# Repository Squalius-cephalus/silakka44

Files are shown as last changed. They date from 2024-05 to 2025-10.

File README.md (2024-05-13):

# Silakka44

Silakka44 is a RP2040 based 44-key column staggered split keyboard. PCB uses hotswap sockets. Design is inpired from REVIUNG41 and Corne keyboards.

PCB is designed for MX style key switches. Current top plate only supports MX style switches. 5-pin switches is supported.

[QMK](https://github.com/qmk/qmk_firmwarehttp:// "QMK") and [Vial](https://github.com/vial-kb/vial-qmk "Vial") firmwares has very barebones key mapping. Good for quick testing.

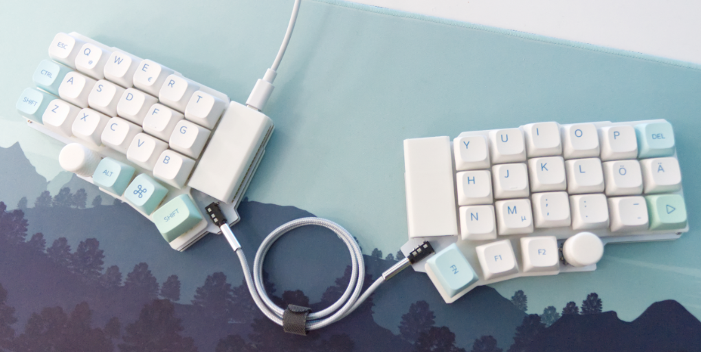
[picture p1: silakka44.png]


You can find build guide [here.](https://github.com/Squalius-cephalus/silakka44/blob/main/buildguide/README.md "here.")

PCB design uses footprints from [ScottoKeebs](https://github.com/joe-scotto/scottokeebs/tree/main/Extras/ScottoKicad "ScottoKeebs") and [kbd library.](https://github.com/foostan/kbd "kbd library.")

### Bugs
Sometimes the encoder buttons are "stuck" when the keyboard is connected to the computer. Pressing those once fixes the problem.

### TODO
1. Redo traces
2. Fix bugs

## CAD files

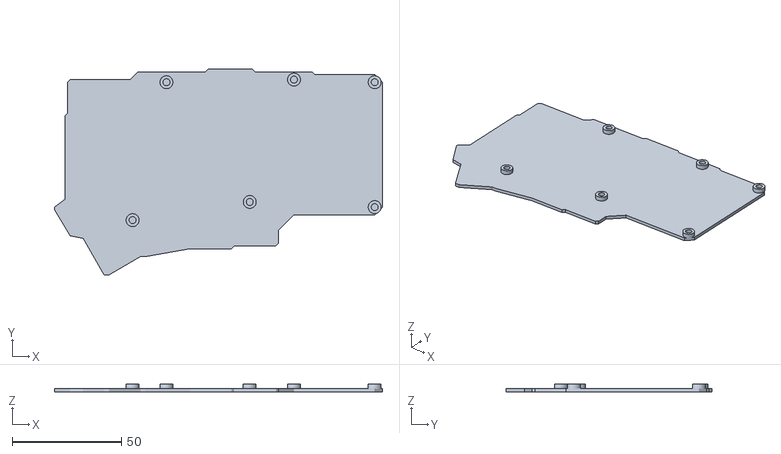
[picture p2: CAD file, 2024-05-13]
stl/silakka42_bottom_right.stl
150.0 x 94.0 x 3.76

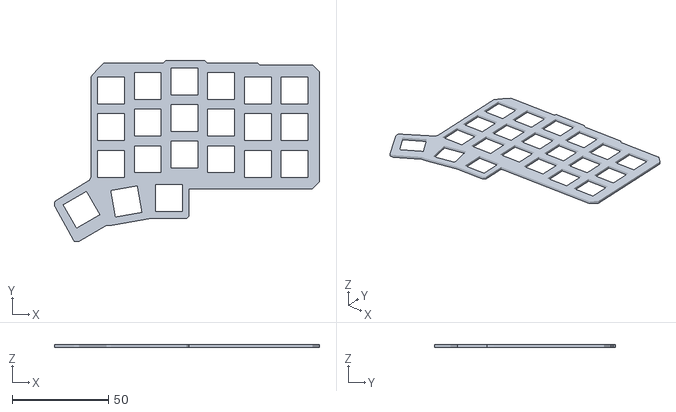
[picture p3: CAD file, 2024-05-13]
stl/silakka44_top_right.stl
137.6 x 94.0 x 1.50

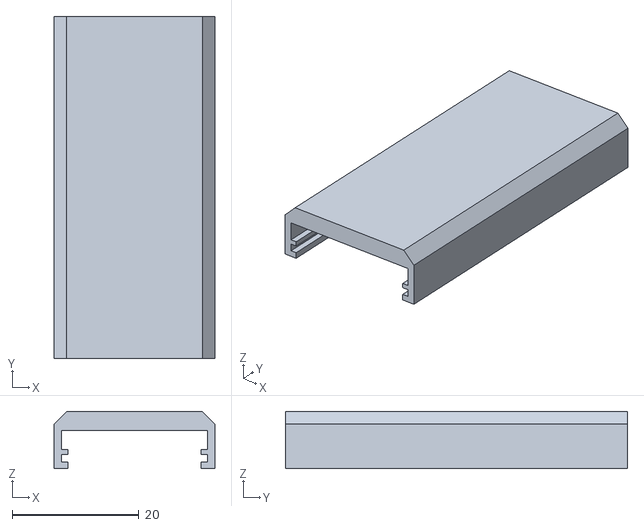
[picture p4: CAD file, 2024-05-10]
stl/raspberry_pi_pico_cover.stl
25.4 x 54.0 x 9.00

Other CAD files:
stl/silakka42_bottom_left.stl
stl/silakka44_top_left.stl

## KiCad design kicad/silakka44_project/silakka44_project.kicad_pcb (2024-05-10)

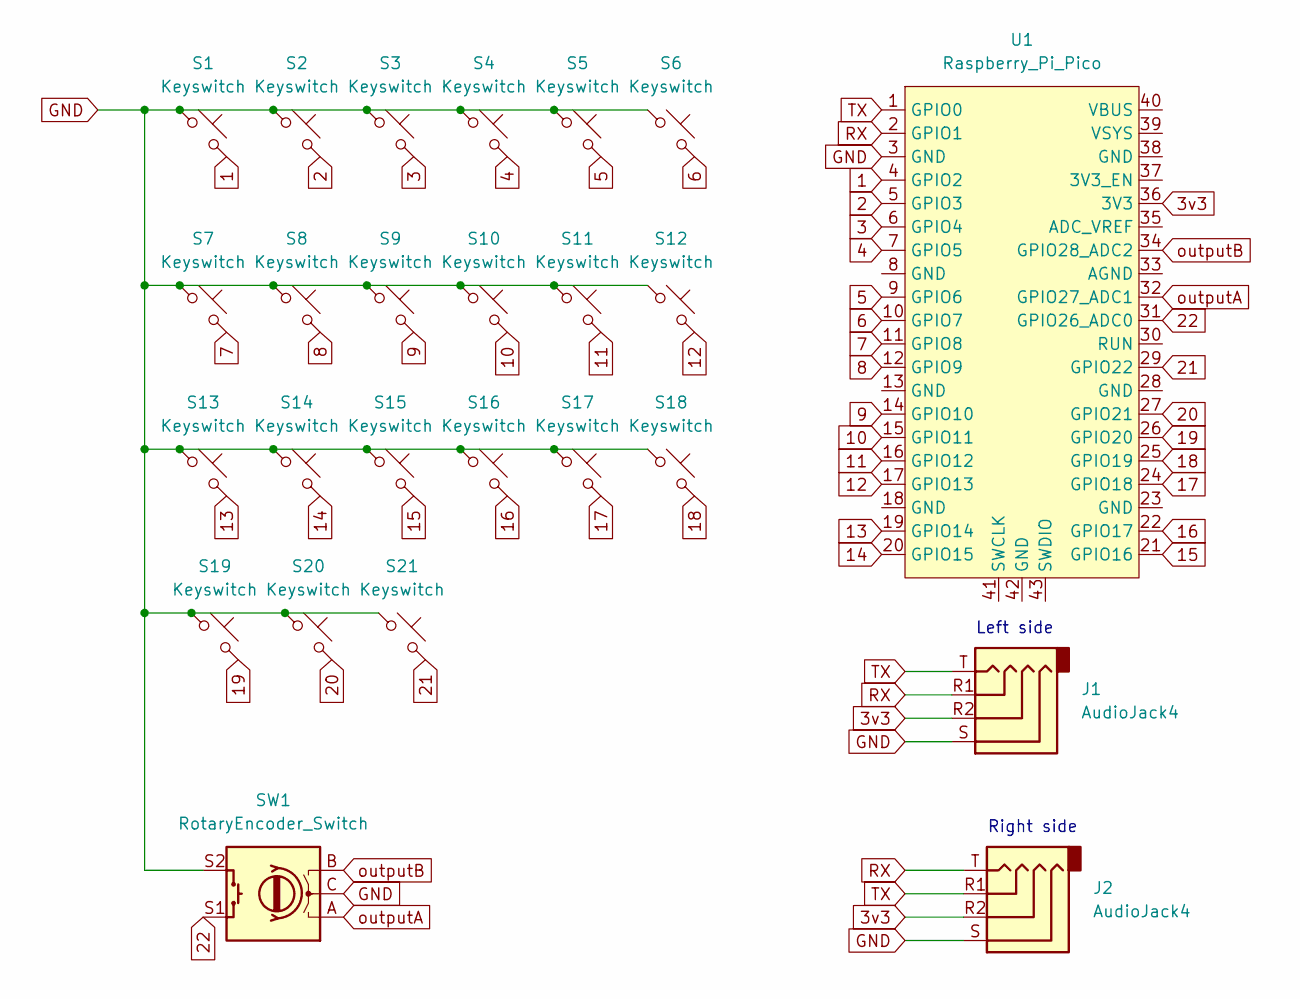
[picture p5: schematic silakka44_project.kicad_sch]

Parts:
J1, J2: AudioJack4; Jack_3.5mm_PJ320D_Horizontal
S1, S2, S3, S4, S5, S6, S7, S8, S9, S10, S11, S12, S13, S14, S15, S16, S17, S18, S19, S20, S21: Keyswitch; CherryMX_MidHeight_Hotswap
SW1: RotaryEncoder_Switch; RotaryEncoder_EC11
U1: Raspberry_Pi_Pico

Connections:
1: S1.2, U1.4 (GPIO2)
2: S2.2, U1.5 (GPIO3)
3: S3.2, U1.6 (GPIO4)
3v3: J1.R2, J2.R2, U1.36 (3V3)
4: S4.2, U1.7 (GPIO5)
5: S5.2, U1.9 (GPIO6)
6: S6.2, U1.10 (GPIO7)
7: S7.2, U1.11 (GPIO8)
8: S8.2, U1.12 (GPIO9)
9: S9.2, U1.14 (GPIO10)
10: S10.2, U1.15 (GPIO11)
11: S11.2, U1.16 (GPIO12)
12: S12.2, U1.17 (GPIO13)
13: S13.2, U1.19 (GPIO14)
14: S14.2, U1.20 (GPIO15)
15: S15.2, U1.21 (GPIO16)
16: S16.2, U1.22 (GPIO17)
17: S17.2, U1.24 (GPIO18)
18: S18.2, U1.25 (GPIO19)
19: S19.2, U1.26 (GPIO20)
20: S20.2, U1.27 (GPIO21)
21: S21.2, U1.29 (GPIO22)
22: SW1.S1, U1.31 (GPIO26_ADC0)
GND: J1.S, J2.S, S1.1, S2.1, S3.1, S4.1, S5.1, S6.1, S7.1, S8.1, S9.1, S10.1, S11.1, S12.1, S13.1, S14.1, S15.1, S16.1, S17.1, S18.1, S19.1, S20.1, S21.1, SW1.C, SW1.S2, U1.3 (GND)
RX: J1.R1, J2.T, U1.2 (GPIO1)
TX: J1.T, J2.R1, U1.1 (GPIO0)
outputA: SW1.A, U1.32 (GPIO27_ADC1)
outputB: SW1.B, U1.34 (GPIO28_ADC2)

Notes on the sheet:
Right side
Left side

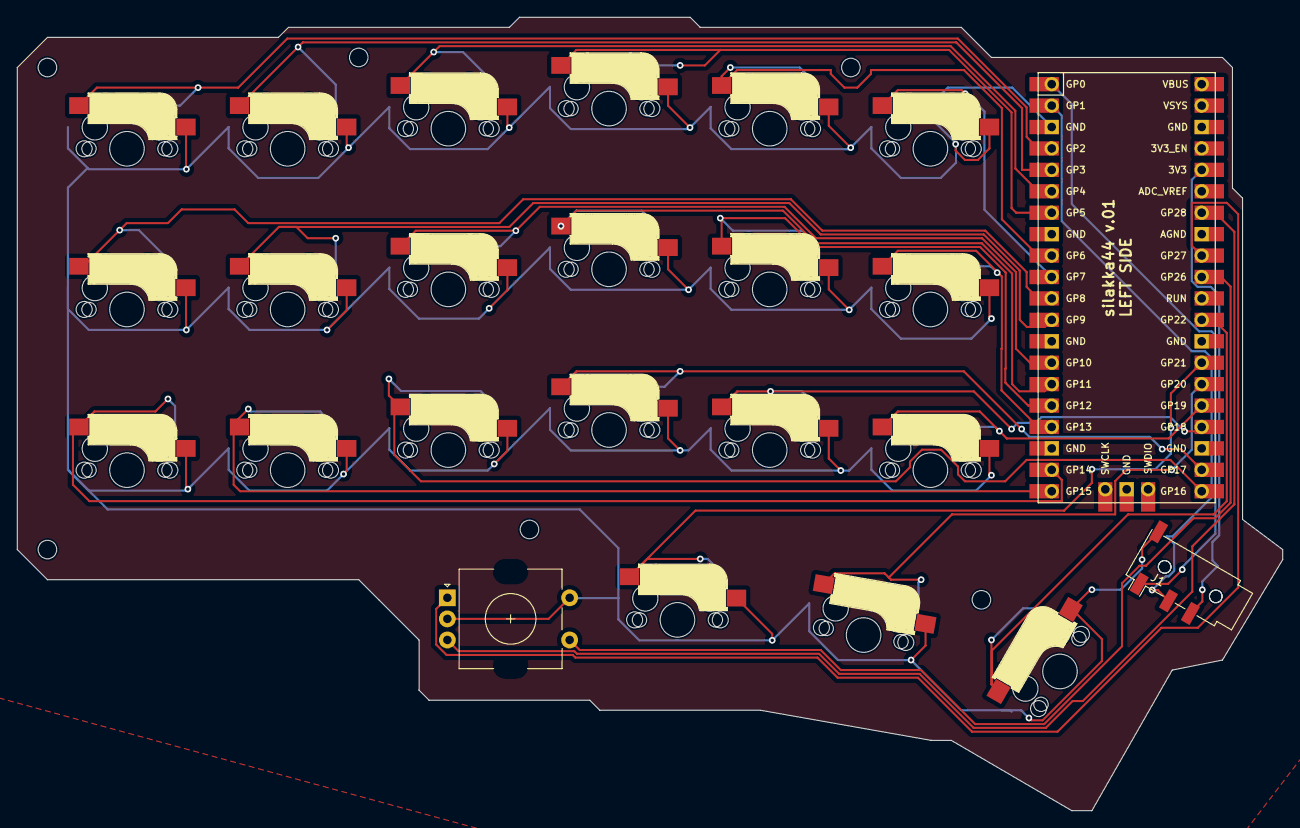
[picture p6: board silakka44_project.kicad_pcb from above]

Board: 2 copper layers, 150.0 x 94.1 mm, 25 parts (1 on the bottom side), 28 nets.

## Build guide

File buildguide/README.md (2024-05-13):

# Silakka44 - Build Guide

### Bill of materials
- **42x** MX compatible key switches
- **40x** 1u keycaps
- **2x** 1.5u keycap
- **42x** Kailh Hotswap Sockets
- **2x** Raspberry Pi Pico or pin compatible clone
- **2x** PJ320D audio sockets
- **2x** EC11 encoders
- **1x** TRRS audio cable
- **12x** M2 Heat set inserts, length 2mm(OD3.2mm)
- **12x** M2 bolts, length 4mm
- **2x** PCB
- **2x** Bottom plate
- **2x** Top plate

I recommend using encoders with D staff.  It's much easier to model or find compatible 3D printed knobs, tolerances don't have to be so good.

STL files do not require support, PLA plastic works well and printing of parts has been tested with a 0.4mm nozzle. Insert the heat set inserts into the bottom plates using a soldering iron.

The PCB is designed so that it can be used on both sides. Use the images as a reference.
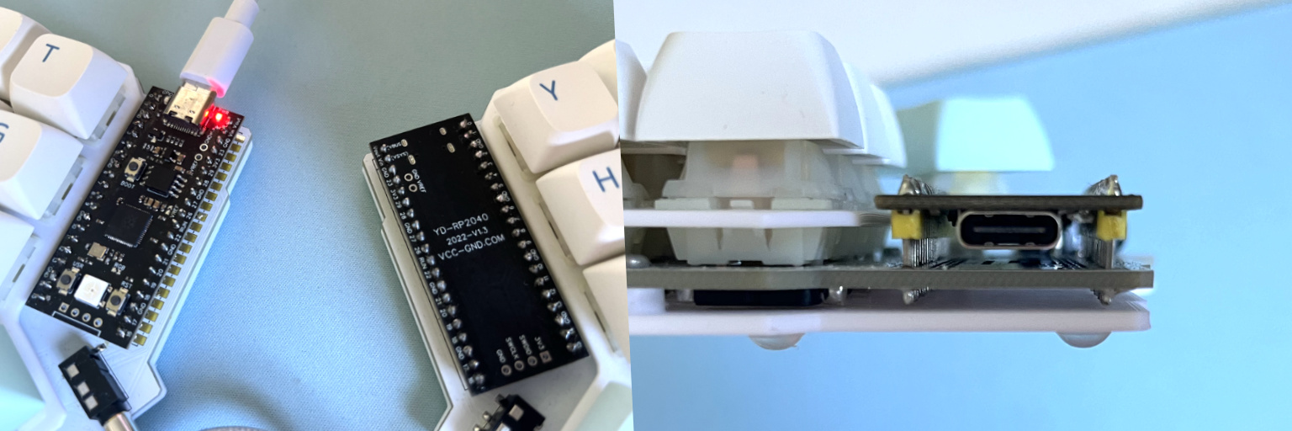
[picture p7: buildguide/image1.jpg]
Use a non-conductive tool to press buttons

The right side Pi Pico needs to be flipped. Don't solder it too close to the PCB, leave a two-millimeter gap, the legs of the pin header should be long enough. There is no RESET pin on the Pi Pico, so you need to have access to RESET and BOOT buttons if you want to change/upload the firmware.

**It is recommended that the firmware is already installed on the Pi Pico, the uf2 file can be found in the firmware folder. Double pressing the RESET button should put the Pico into bootloader mode if the firmware is installed.**

Solder the hotswap sockets, TRRS sockets, EC11 encoders, hotswap sockets and Pi Pico's. Connect the two halves with the TRRS cable. Never connect or disconnect TRRS cable when keyboard is powered. This can lead to a short circuit.
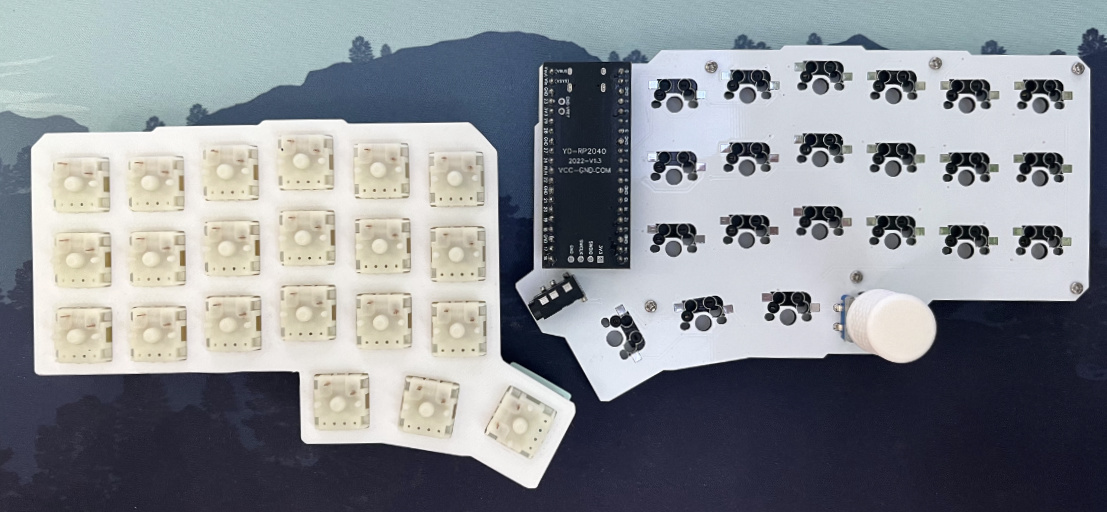
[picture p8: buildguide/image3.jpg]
Check the pins!

Next, attach the PCB to the plate with bolts. Then you can attach the switches to the top plate. Once all the switches are in place, make sure that the switch pins are not twisted or damaged. Press the top plate with the switches to the PCB.
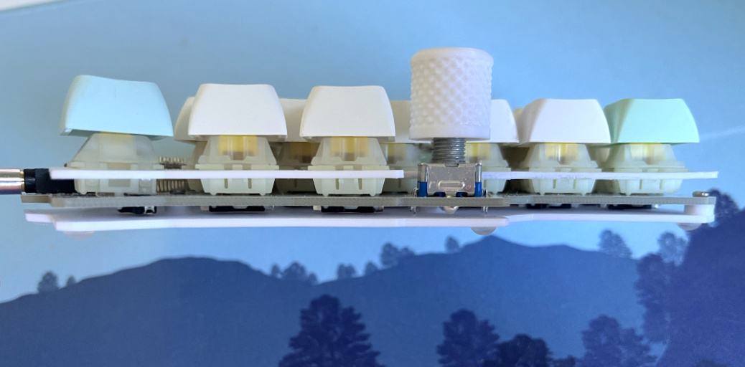
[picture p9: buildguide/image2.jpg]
I recommend putting small rubber feet on the bottom plate. If you installed the silakka44_vial firmware, you can use the Vial software to test the functionality of the switches in the matrix tester.

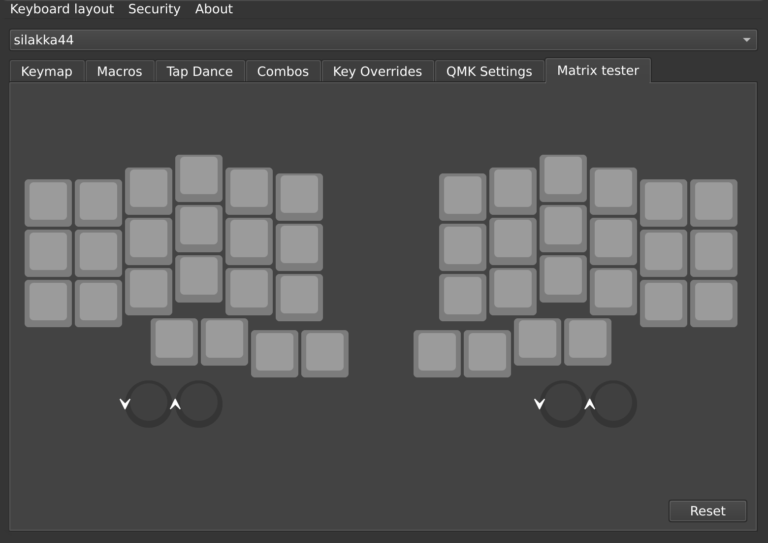
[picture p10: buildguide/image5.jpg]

The current firmware does not support matrix testing for encoders.

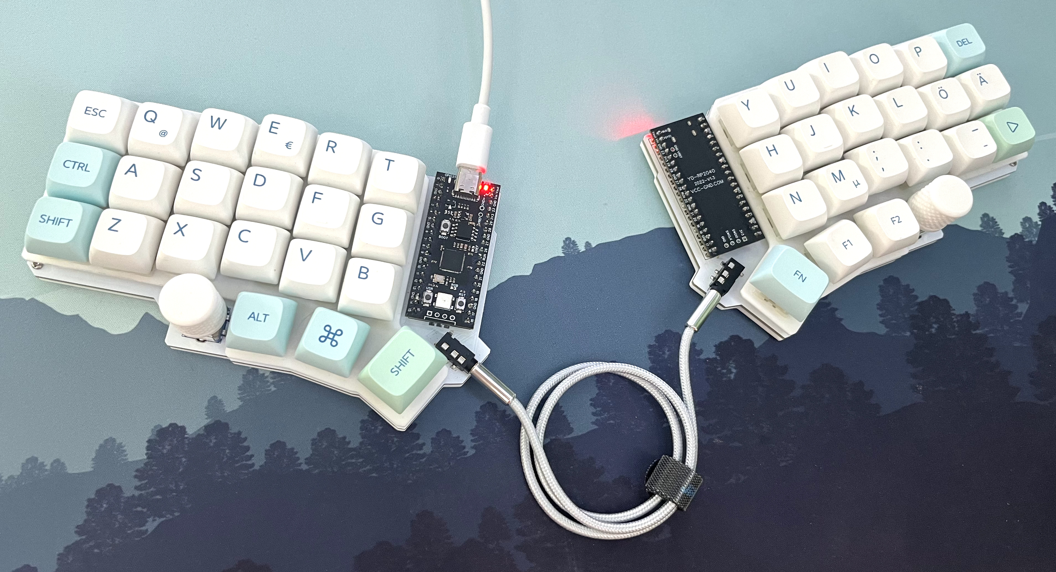
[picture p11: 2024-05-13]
buildguide/image4.jpg

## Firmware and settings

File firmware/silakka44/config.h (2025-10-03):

#pragma once

#define SERIAL_USART_FULL_DUPLEX
#define SERIAL_USART_TX_PIN GP0
#define SERIAL_USART_RX_PIN GP1

#define ENCODER_A_PINS { GP27 }
#define ENCODER_B_PINS { GP28 }


#define ENCODER_A_PINS_RIGHT { GP27 }
#define ENCODER_B_PINS_RIGHT { GP28 }

// Change this to MASTER_RIGHT if you want to use right side USB
#define MASTER_LEFT

#define RP2040_BOOTLOADER_DOUBLE_TAP_RESET
#define RP2040_BOOTLOADER_DOUBLE_TAP_RESET_TIMEOUT 200U
#define RP2040_BOOTLOADER_DOUBLE_TAP_RESET_LED GP17

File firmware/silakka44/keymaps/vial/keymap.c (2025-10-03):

// Copyright 2024 Squalius-cephalus (@Squalius-cephalus)
// SPDX-License-Identifier: GPL-2.0-or-later

#include QMK_KEYBOARD_H

const uint16_t PROGMEM keymaps[][MATRIX_ROWS][MATRIX_COLS] = {
    /*
     * Edit this
     */
    [0] = LAYOUT_ortho_4x12(
        KC_TAB,    KC_Q,    KC_W,    KC_E,    KC_R,    KC_T,    KC_Y,    KC_U,    KC_I,    KC_O,    KC_P,    KC_BACKSPACE,
        KC_LCTL,    KC_A,    KC_S,    KC_D,    KC_F,    KC_G,    KC_H,    KC_J,    KC_K,    KC_L,    KC_SCLN,    KC_QUOT,
        KC_LSFT,    KC_Z,    KC_X,    KC_C,    KC_V,    KC_B,    KC_N,    KC_M,    KC_COMM,    KC_DOT,    KC_SLSH,    KC_ENT,
        KC_RALT,       KC_LALT,    KC_LGUI,    KC_SPACE,    KC_NO,    KC_NO,    KC_A,    KC_B,    KC_C,    KC_D,    KC_NO,    KC_NO
    ),
        [1] = LAYOUT_ortho_4x12(
        KC_TAB,    KC_Q,    KC_W,    KC_E,    KC_R,    KC_T,    KC_Y,    KC_U,    KC_I,    KC_O,    KC_P,    KC_BACKSPACE,
        KC_LCTL,    KC_A,    KC_S,    KC_D,    KC_F,    KC_G,    KC_H,    KC_J,    KC_K,    KC_L,    KC_SCLN,    KC_QUOT,
        KC_LSFT,    KC_Z,    KC_X,    KC_C,    KC_V,    KC_B,    KC_N,    KC_M,    KC_COMM,    KC_DOT,    KC_SLSH,    KC_ENT,
        KC_RALT,       KC_LALT,    KC_LGUI,    KC_SPACE,    KC_NO,    KC_NO,    KC_A,    KC_B,    KC_C,    KC_D,    KC_NO,    KC_NO
    ),
        [2] = LAYOUT_ortho_4x12(
        KC_TAB,    KC_Q,    KC_W,    KC_E,    KC_R,    KC_T,    KC_Y,    KC_U,    KC_I,    KC_O,    KC_P,    KC_BACKSPACE,
        KC_LCTL,    KC_A,    KC_S,    KC_D,    KC_F,    KC_G,    KC_H,    KC_J,    KC_K,    KC_L,    KC_SCLN,    KC_QUOT,
        KC_LSFT,    KC_Z,    KC_X,    KC_C,    KC_V,    KC_B,    KC_N,    KC_M,    KC_COMM,    KC_DOT,    KC_SLSH,    KC_ENT,
        KC_RALT,       KC_LALT,    KC_LGUI,    KC_SPACE,    KC_NO,    KC_NO,    KC_A,    KC_B,    KC_C,    KC_D,    KC_NO,    KC_NO
        ),
            [3] = LAYOUT_ortho_4x12(
        KC_TAB,    KC_Q,    KC_W,    KC_E,    KC_R,    KC_T,    KC_Y,    KC_U,    KC_I,    KC_O,    KC_P,    KC_BACKSPACE,
        KC_LCTL,    KC_A,    KC_S,    KC_D,    KC_F,    KC_G,    KC_H,    KC_J,    KC_K,    KC_L,    KC_SCLN,    KC_QUOT,
        KC_LSFT,    KC_Z,    KC_X,    KC_C,    KC_V,    KC_B,    KC_N,    KC_M,    KC_COMM,    KC_DOT,    KC_SLSH,    KC_ENT,
        KC_RALT,       KC_LALT,    KC_LGUI,    KC_SPACE,    KC_NO,    KC_NO,    KC_A,    KC_B,    KC_C,    KC_D,    KC_NO,    KC_NO
    )




};



#if defined(ENCODER_MAP_ENABLE)
const uint16_t PROGMEM encoder_map[][NUM_ENCODERS][2] = {
    [0] =   { ENCODER_CCW_CW(KC_MS_WH_UP, KC_MS_WH_DOWN), ENCODER_CCW_CW(KC_VOLD, KC_VOLU)  },
    [1] =   { ENCODER_CCW_CW(KC_MS_WH_UP, KC_MS_WH_DOWN),           ENCODER_CCW_CW(KC_VOLD, KC_VOLU)  },
    [2] =   { ENCODER_CCW_CW(KC_MS_WH_UP, KC_MS_WH_DOWN),           ENCODER_CCW_CW(KC_VOLD, KC_VOLU)  },
    [3] =   { ENCODER_CCW_CW(KC_MS_WH_UP, KC_MS_WH_DOWN),          ENCODER_CCW_CW(KC_VOLD, KC_VOLU) },
    //                  Encoder 1                                     Encoder 2
};
#endif

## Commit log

2024-05-10 Initial commit
    Includes STL files, firmware, KiCAD project and gerber files.
    [raspberry_pi_pico_cover.stl, silakka42_bottom.stl, silakka44_project.kicad_pcb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]
2024-05-13 Updated STL files
    [silakka42_bottom.stl, silakka42_bottom_left.stl, silakka42_bottom_right.stl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]
2025-10-03 Rotary encoders fixed
